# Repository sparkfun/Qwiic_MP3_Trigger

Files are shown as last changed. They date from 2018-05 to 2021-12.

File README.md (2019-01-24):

SparkFun Qwiic MP3 Trigger
========================================

SparkFun Qwiic MP3 Trigger

[*SparkFun Qwiic MP3 Trigger (DEV-15165)*](https://www.sparkfun.com/products/15165)

This repo is the hardware repo for the Qwiic MP3 Trigger.

Sometimes you just need an MP3 to play. Whether it's a theme song as you enter the room or a pirate cackling when a dollar [gets donated](https://github.com/nseidle/Money_Vacuum) to the kid's museum. The Qwiic MP3 Trigger takes care of all the necessary bits, all you need to do is send a simple I2C command and listen.

The Qwiic MP3 Trigger comes loaded with everything a user may need. Connecting a USB C cable enumerates the Qwiic MP3 Trigger as a jump drive. Simply plug in the Qwiic MP3 Trigger and you'll be transferring MP3s. No need for drivers and no need for WAV or Vorbis conversion! Sound output is provided via a headphone jack or poke-home connector allowing an external speaker to be connected without soldering. The speaker is boosted by a Class-D mono amplifier capable of outputting up to 1.4W. What does 1.4W mean? It's incredibly loud; great for making sure your mech effects are heard on the *con floor and wonderful for annoying your officemates. Volume is software selectable between 32 levels. Equalization can be tuned to be sure your classical hits sound different from your jazz dance routines (in all seriousness EQ selection is available but it's pretty paltry).

And if you don't want to deal with *any* programming, there are four trigger pins. When pin 3 is pulled low the T003.mp3 file will immediately be played. This allows you to start playing sound effects with the touch of a button! By pulling multiple pins down simultaneously the four triggers can play up to ten tracks: T001 to T010.

All settings including volume, EQ, and I2C address are stored in NVM and loaded at each power up. The I2C address of the Qwiic MP3 Trigger can be modified via a solder jumper or be assigned using a software command. Multiple Qwiic MP3 Triggers can be chained together on a single bus allowing for simultaneous track mixing and triggering.

We've written an extensive Arduino library to make MP3 playing over I2C a breeze. Play track X, change volume, play next/previous, check if track is playing, stop play, change EQ, and change I2C address are all supported.

The I2C address of Qwiic MP3 Trigger is software configurable which means you can hookup over 100 on a single I2C bus!

This board is one of our many [Qwiic](https://www.sparkfun.com/qwiic) compatible boards! Simply plug and go. No soldering, no figuring out which is SDA or SCL, and no voltage regulation or translation required!

SparkFun labored with love to create this code. Feel like supporting open source hardware? 
Buy a [breakout board](https://www.sparkfun.com/products/15165) from SparkFun!

Repository Contents
-------------------

* **/Documents** - Datasheets
* **/Hardware** - Eagle design files (.brd, .sch)

Documentation
--------------
* **[Qwiic MP3 Trigger Hookup Guide](https://learn.sparkfun.com/tutorials/qwiic-mp3-trigger-hookup-guide)** - Hookup guide for the Qwiic MP3 Trigger
* **[Installing an Arduino Library Guide](https://learn.sparkfun.com/tutorials/installing-an-arduino-library)** - Basic information on how to install an Arduino library.
* **[Arduino Library](https://github.com/sparkfun/SparkFun_Qwiic_MP3_Trigger_Arduino_Library)** - Library if you decide to use an Arduino via serial I2C.

License Information
-------------------

This product is _**open source**_! 

If you have any questions or concerns on licensing, please contact techsupport@sparkfun.com.

Please use, reuse, and modify these files as you see fit. Please maintain attribution to SparkFun Electronics and release any derivative under the same license.

Distributed as-is; no warranty is given.

- Your friends at SparkFun.

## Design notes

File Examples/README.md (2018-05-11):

SparkFun Qwiic MP3 Trigger
========================================

These various example sketches for Arduino demostrating how to use the Qwiic MP3 Trigger.

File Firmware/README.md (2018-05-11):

SparkFun Qwiic MP3 Trigger
========================================

This is the production firmware loaded onto the ATtiny84 on the QMP3T. The tester is an Arduino sketch used in production which causes the QMP3T to start playing. It's helpful to verify all the bits of the board are working.

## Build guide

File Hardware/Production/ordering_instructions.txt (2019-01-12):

panel size, 244x116mm
PCB thickness, 1.6mm
number of layers, 2
soldermask color, Red
silkscreen color, White
oz copper, 1oz
finish, HASL lead free
stencils, top
pcs per panel, 16

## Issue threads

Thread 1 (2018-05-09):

P10 pin not working

nseidle, 2018-05-09:
Pin is low at power up. Goes high during play. But stays high after song is stopped. This causes the amp to stay enabled after a song is complete and causes buzzing.

The BUSY pin does work as expected. Perhaps we wire the BUSY pin to the amp SDN pin.

nseidle, 2018-11-29:
Should be fixed on v10

Closed 2018-11-29.

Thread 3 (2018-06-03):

Documentation in firmware has incorrect i2c command values

querry43, 2018-06-03:
The comment header for Qwiic_MP3_Controller.ino lists the command values incorrectly.  As one example, it has:

> 0x0A : Get firmware version : 2 bytes, upper ver and lower ver

when the actual value is:

> #define COMMAND_GET_VERSION 0x0C

nseidle, 2018-06-04:
Good catch! Thanks for reporting the issue. I think I've updated the main firmware ino with the correct commands. Let me know if there's anything else that has issues.

Closed 2018-06-04.

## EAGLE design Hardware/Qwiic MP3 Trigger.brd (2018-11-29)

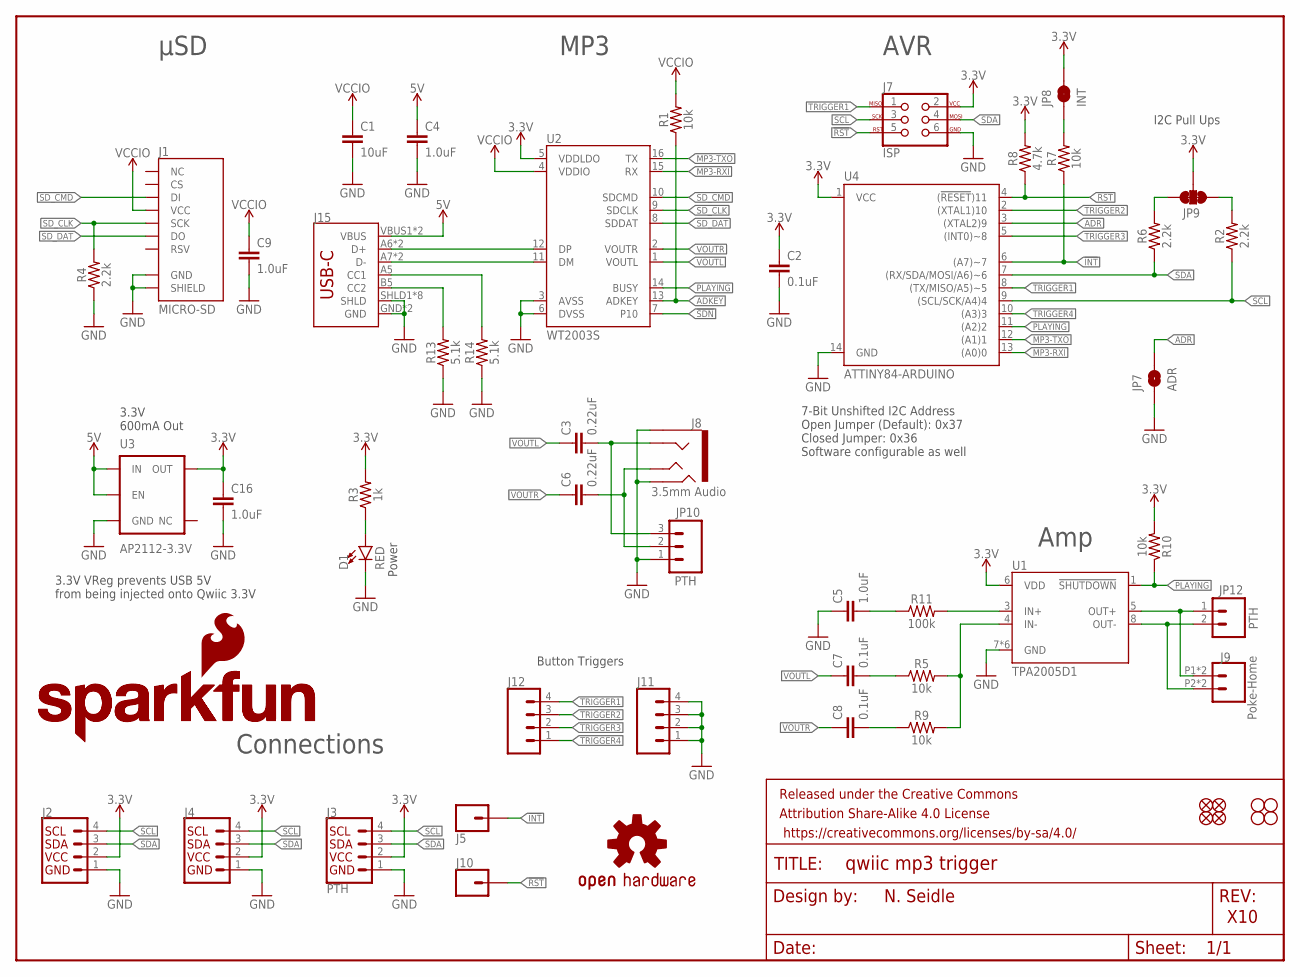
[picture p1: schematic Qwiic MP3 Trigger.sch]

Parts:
C1: 10uF; 0603
C2, C7, C8: 0.1uF; 0603
C3, C6: 0.22uF; 0603
C4, C5, C9, C16: 1.0uF; 0603
D1: RED; LED-0603
FRAME1: FRAME-LETTER; CREATIVE_COMMONS
J1: MICRO-SD; MICRO-SD-SOCKET
J2, J4: QWIIC_CONNECTORJS-1MM; 1X04_1MM_RA
J3: PTH; 1X04_NO_SILK
J5, J10: CONN_01PTH_NO_SILK_YES_STOP; 1X01_NO_SILK
J7: ISP; 2X3_TEST_POINTS
J8: 3.5mm Audio; AUDIO_JACK_3.5MM_TRRS_SMD_RA
J9: Poke-Home; 1X02_POKEHOME
J11, J12: CONN_041X04_NO_SILK; 1X04_NO_SILK
J15: USB_C16PIN; USB-C-16P
JP1, JP2, JP5, JP6: FIDUCIALUFIDUCIAL; MICRO-FIDUCIAL
JP3, JP4, JP11, JP13: STAND-OFF
JP7: ADR; SMT-JUMPER_2_NO_SILK
JP8: INT; SMT-JUMPER_2_NC_TRACE_SILK
JP9: JUMPER-SMT_3_2-NC_TRACE_SILK; SMT-JUMPER_3_2-NC_TRACE_SILK
JP10: PTH; 1X03_NO_SILK
JP12: PTH; 1X02_NO_SILK
LOGO1: OSHW-LOGOMINI; OSHW-LOGO-MINI
LOGO2: SFE_LOGO_NAME.1_INCH; SFE_LOGO_NAME_.1
LOGO3: SFE_LOGO_NAME_FLAME.1_INCH; SFE_LOGO_NAME_FLAME_.1
R1, R5, R7, R9, R10: 10k; 0603
R2, R4, R6: 2.2k; 0603
R3: 1k; 0603
R8: 4.7k; 0603
R11: 100k; 0603
R13, R14: 5.1k; 0603
U1: TPA2005D1; QFN-8_PAD
U2: WT2003S; SO16
U3: AP2112-3.3V; SOT23-5
U4: ATTINY84-ARDUINO; SO14

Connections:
3.3V: C2.1, C16.1, J2.2, J3.2 (VCC), J4.2, J7.2, JP8.2, JP9.2, R3.2, R8.2, R10.2, U1.6 (VDD), U2.5 (VDDLDO), U3.5 (OUT), U4.1 (VCC)
5V: C4.1, J15.VBUS1 (VBUS), J15.VBUS2 (VBUS), U3.1 (IN), U3.3 (EN)
!INT: J5.1, R7.1, U4.6 ((A7)~7)
!RST: J7.5, J10.1, R8.1, U4.4 ((!RESET!)11)
!SDN: U2.7 (P10)
AC-L: C3.2, J8.RING1, JP10.3
AC-R: C6.2, J8.TIP, JP10.2
ADKEY: R1.1, U2.13 (ADKEY)
ADR: JP7.2, U4.3 ((XTAL2)9)
D+: J15.A6 (D+), J15.B6 (D+), U2.12 (DP)
D-: J15.A7 (D-), J15.B7 (D-), U2.11 (DM)
GND: C1.2, C2.2, C4.2, C5.1, C9.2, C16.2, D1.C, J1.CD1 (SHIELD), J1.GND, J2.1, J3.1 (GND), J4.1, J7.6, J8.EARTH, J8.RING2, J11.1, J11.2, J11.3, J11.4, J15.GND, J15.GND2 (GND), J15.SHLD1 (SHLD), J15.SHLD2 (SHLD), J15.SHLD3 (SHLD), J15.SHLD4 (SHLD), J15.SHLD5 (SHLD), J15.SHLD6 (SHLD), J15.SHLD7 (SHLD), J15.SHLD8 (SHLD), JP7.1, JP10.1, R4.1, R13.1, R14.1, U1.7 (GND), U1.9 (GND), U1.10 (GND), U1.11 (GND), U1.12 (GND), U1.13 (GND), U2.3 (AVSS), U2.6 (DVSS), U3.2 (GND), U4.14 (GND)
IN+AMP: R11.2, U1.3 (IN+)
IN-AMP: R5.2, R9.2, U1.4 (IN-)
MP3-RXI: U2.15 (RX), U4.13 ((A0)0)
MP3-TXO: U2.16 (TX), U4.12 ((A1)1)
unnamed: J15.B5 (CC2), R13.2
unnamed: J15.A5 (CC1), R14.2
unnamed: D1.A, R3.1
unnamed: JP8.1, R7.2
unnamed: C8.2, R9.1
unnamed: C5.2, R11.1
unnamed: C7.2, R5.1
OUT+: J9.P1 (1), J9.P3 (1), JP12.1, U1.5 (OUT+)
OUT-: J9.P2 (2), J9.P4 (2), JP12.2, U1.8 (OUT-)
PLAYING: R10.1, U1.1 (!SHUTDOWN), U2.14 (BUSY), U4.11 ((A2)2)
SCL: J2.4, J3.4 (SCL), J4.4, J7.3, R2.1, U4.9 ((SCL/SCK/A4)4)
SCL_PU1: JP9.1, R2.2
SDA: J2.3, J3.3 (SDA), J4.3, J7.4, R6.1, U4.7 ((RX/SDA/MOSI/A6)~6)
SDA_PU1: JP9.3, R6.2
SD_CLK: J1.SCLK (SCK), R4.2, U2.9 (SDCLK)
SD_CMD: J1.DI, U2.10 (SDCMD)
SD_DAT: J1.DO, U2.8 (SDDAT)
TRIGGER1: J7.1, J12.4, U4.8 ((TX/MISO/A5)~5)
TRIGGER2: J12.3, U4.2 ((XTAL1)10)
TRIGGER3: J12.2, U4.5 ((INT0)~8)
TRIGGER4: J12.1, U4.10 ((A3)3)
VCCIO: C1.1, C9.1, J1.VCC, R1.2, U2.4 (VDDIO)
VOUTL: C3.1, C7.1, U2.1 (VOUTL)
VOUTR: C6.1, C8.1, U2.2 (VOUTR)

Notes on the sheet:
N. Seidle
X10
Power
7-Bit Unshifted I2C Address Open Jumper (Default): 0x37 Closed Jumper: 0x36 Software configurable as well
I2C Pull Ups
Button Triggers
3.3V VReg prevents USB 5V from being injected onto Qwiic 3.3V
3.3V 600mA Out
μSD
MP3
AVR
Amp
Connections

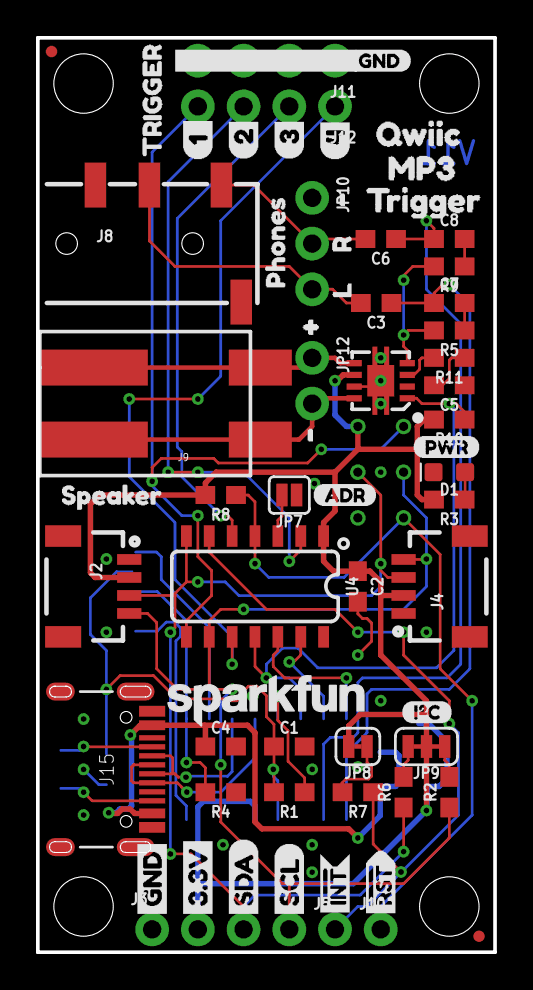
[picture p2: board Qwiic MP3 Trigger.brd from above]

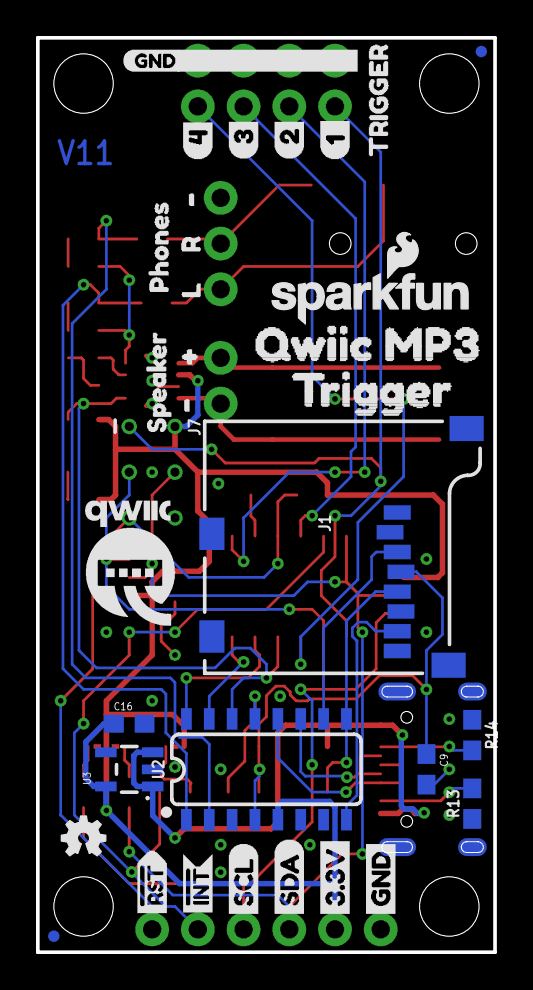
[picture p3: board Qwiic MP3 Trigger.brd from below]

Board: 2 copper layers, 25.4 x 50.8 mm, 104 parts (34 on the bottom side), 39 nets.

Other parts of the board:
U$1: MP31
U$3, U$22: GND1
U$4, U$21: 3#3V2
U$5, U$27: SDA8
U$6, U$26: SCL9
U$7, U$16: RST#-[>
U$8: I_SUPER2_C-()-03
U$9, U$11: INT#-[<
U$10, U$13, U$25, U$38: #6
U$12, U$28: #5
U$14, U$20: SPEAKER1
U$15, U$40: PHONES0
U$17: PWR-()-03
U$18: ADR-()-03
U$19, U$44: 1_1
U$23: QWIIC0
U$24: QWIIC_MP32
U$29, U$45: TRIGGER5
U$31, U$34: 43
U$32, U$42: 21
U$33, U$36: 32
U$35, U$46: GND0
U$37, U$41: L12
U$39, U$43: R11
U$47: QWIIC-LOGO-MEDIUM
U$49: TRIGGER4
U$50: TRIGGER2

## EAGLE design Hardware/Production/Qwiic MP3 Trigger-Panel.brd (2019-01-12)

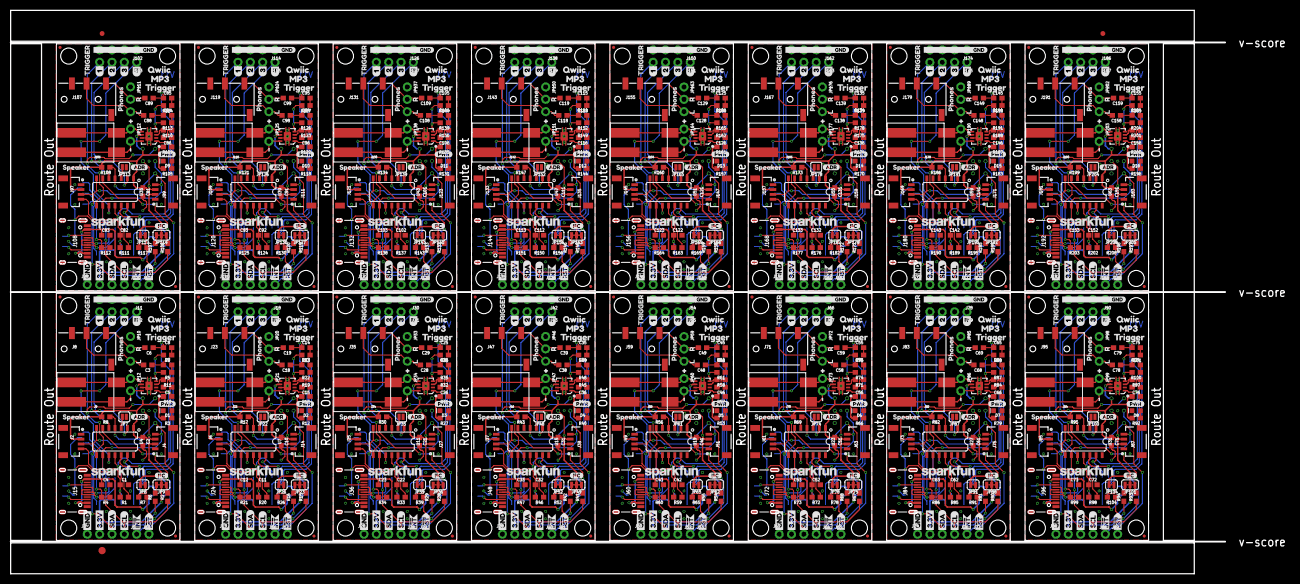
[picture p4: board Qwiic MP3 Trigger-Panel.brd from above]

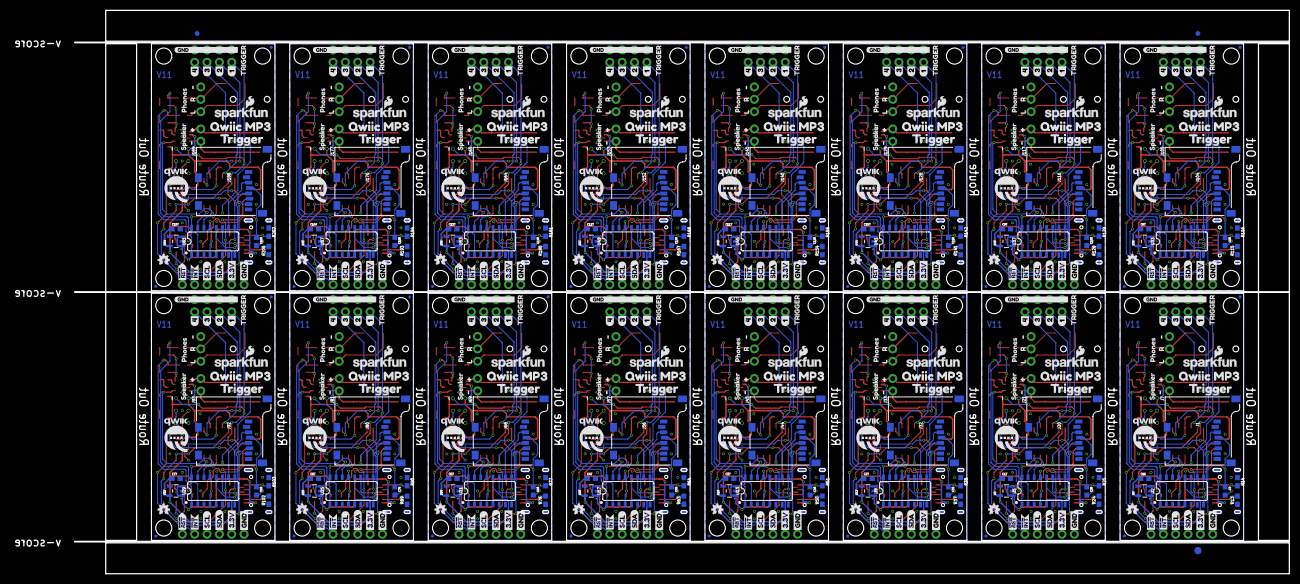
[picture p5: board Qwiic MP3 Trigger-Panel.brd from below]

Board: 2 copper layers, 249.7 x 115.8 mm, 1654 parts (547 on the bottom side), 624 nets.

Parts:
C1, C11, C22, C32, C42, C52, C62, C72, C82, C92, C102, C112, C122, C132, C142, C152: 10uF; 0603
C2, C7, C8, C10, C13, C14, C21, C24, C25, C31, C34, C35, C41, C44, C45, C51, C54, C55, C61, C64, C65, C71, C74, C75, C81, C84, C85, C91, C94, C95, C101, C104, C105, C111, C114, C115, C121, C124, C125, C131, C134, C135, C141, C144, C145, C151, C154, C155: 0.1uF; 0603
C3, C6, C18, C19, C28, C29, C38, C39, C48, C49, C58, C59, C68, C69, C78, C79, C88, C89, C98, C99, C108, C109, C118, C119, C128, C129, C138, C139, C148, C149, C158, C159: 0.22uF; 0603
C4, C5, C9, C12, C15, C16, C17, C20, C23, C26, C27, C30, C33, C36, C37, C40, C43, C46, C47, C50, C53, C56, C57, C60, C63, C66, C67, C70, C73, C76, C77, C80, C83, C86, C87, C90, C93, C96, C97, C100, C103, C106, C107, C110, C113, C116, C117, C120, C123, C126, C127, C130, C133, C136, C137, C140, C143, C146, C147, C150, C153, C156, C157, C160: 1.0uF; 0603
D1, D2, D3, D4, D5, D6, D7, D8, D9, D10, D11, D12, D13, D14, D15, D16: RED; LED-0603
E$1, E$2, E$3, E$4: FIDUCIAL-1X2
E$5, E$6: FIDUCIAL-1.5X3
J1, J20, J32, J44, J56, J68, J80, J92, J104, J116, J128, J140, J152, J164, J176, J188: MICRO-SD; MICRO-SD-SOCKET
J2, J4, J6, J14, J25, J27, J37, J39, J49, J51, J61, J63, J73, J75, J85, J87, J97, J99, J109, J111, J121, J123, J133, J135, J145, J147, J157, J159, J169, J171, J181, J183: 1X04_1MM_RA
J3, J13, J26, J38, J50, J62, J74, J86, J98, J110, J122, J134, J146, J158, J170, J182: PTH; 1X04_NO_SILK
J5, J10, J16, J17, J28, J29, J40, J41, J52, J53, J64, J65, J76, J77, J88, J89, J100, J101, J112, J113, J124, J125, J136, J137, J148, J149, J160, J161, J172, J173, J184, J185: 1X01_NO_SILK
J7, J21, J33, J45, J57, J69, J81, J93, J105, J117, J129, J141, J153, J165, J177, J189: ISP; 2X3_TEST_POINTS
J8, J23, J35, J47, J59, J71, J83, J95, J107, J119, J131, J143, J155, J167, J179, J191: 3.5mm Audio; AUDIO_JACK_3.5MM_TRRS_SMD_RA
J9, J22, J34, J46, J58, J70, J82, J94, J106, J118, J130, J142, J154, J166, J178, J190: Poke-Home; 1X02_POKEHOME
J11, J12, J18, J19, J30, J31, J42, J43, J54, J55, J66, J67, J78, J79, J90, J91, J102, J103, J114, J115, J126, J127, J138, J139, J150, J151, J162, J163, J174, J175, J186, J187: 1X04_NO_SILK
J15, J24, J36, J48, J60, J72, J84, J96, J108, J120, J132, J144, J156, J168, J180, J192: USB-C-16P
JP1, JP2, JP5, JP6, JP16, JP17, JP18, JP19, JP29, JP30, JP31, JP32, JP42, JP43, JP44, JP45, JP55, JP56, JP57, JP58, JP68, JP69, JP70, JP71, JP81, JP82, JP83, JP84, JP94, JP95, JP96, JP97, JP107, JP108, JP109, JP110, JP120, JP121, JP122, JP123, JP133, JP134, JP135, JP136, JP146, JP147, JP148, JP149, JP159, JP160, JP161, JP162, JP172, JP173, JP174, JP175, JP185, JP186, JP187, JP188, JP198, JP199, JP200, JP201: FIDUCIALUFIDUCIAL; MICRO-FIDUCIAL
JP3, JP4, JP11, JP13, JP14, JP15, JP24, JP25, JP27, JP28, JP37, JP38, JP40, JP41, JP50, JP51, JP53, JP54, JP63, JP64, JP66, JP67, JP76, JP77, JP79, JP80, JP89, JP90, JP92, JP93, JP102, JP103, JP105, JP106, JP115, JP116, JP118, JP119, JP128, JP129, JP131, JP132, JP141, JP142, JP144, JP145, JP154, JP155, JP157, JP158, JP167, JP168, JP170, JP171, JP180, JP181, JP183, JP184, JP193, JP194, JP196, JP197, JP206, JP207: STAND-OFF
JP7, JP22, JP35, JP48, JP61, JP74, JP87, JP100, JP113, JP126, JP139, JP152, JP165, JP178, JP191, JP204: ADR; SMT-JUMPER_2_NO_SILK
JP8, JP26, JP39, JP52, JP65, JP78, JP91, JP104, JP117, JP130, JP143, JP156, JP169, JP182, JP195, JP208: INT; SMT-JUMPER_2_NC_TRACE_SILK
JP9, JP23, JP36, JP49, JP62, JP75, JP88, JP101, JP114, JP127, JP140, JP153, JP166, JP179, JP192, JP205: SMT-JUMPER_3_2-NC_TRACE_SILK
JP10, JP20, JP33, JP46, JP59, JP72, JP85, JP98, JP111, JP124, JP137, JP150, JP163, JP176, JP189, JP202: PTH; 1X03_NO_SILK
JP12, JP21, JP34, JP47, JP60, JP73, JP86, JP99, JP112, JP125, JP138, JP151, JP164, JP177, JP190, JP203: PTH; 1X02_NO_SILK
LOGO1, LOGO4, LOGO7, LOGO10, LOGO13, LOGO16, LOGO19, LOGO22, LOGO25, LOGO28, LOGO31, LOGO34, LOGO37, LOGO40, LOGO43, LOGO46: OSHW-LOGOMINI; OSHW-LOGO-MINI
LOGO2, LOGO5, LOGO8, LOGO11, LOGO14, LOGO17, LOGO20, LOGO23, LOGO26, LOGO29, LOGO32, LOGO35, LOGO38, LOGO41, LOGO44, LOGO47: SFE_LOGO_NAME.1_INCH; SFE_LOGO_NAME_.1
LOGO3, LOGO6, LOGO9, LOGO12, LOGO15, LOGO18, LOGO21, LOGO24, LOGO27, LOGO30, LOGO33, LOGO36, LOGO39, LOGO42, LOGO45, LOGO48: SFE_LOGO_NAME_FLAME.1_INCH; SFE_LOGO_NAME_FLAME_.1
R1, R5, R7, R9, R10, R18, R20, R22, R23, R26, R31, R33, R35, R36, R39, R44, R46, R48, R49, R52, R57, R59, R61, R62, R65, R70, R72, R74, R75, R78, R83, R85, R87, R88, R91, R96, R98, R100, R101, R104, R109, R111, R113, R114, R117, R122, R124, R126, R127, R130, R135, R137, R139, R140, R143, R148, R150, R152, R153, R156, R161, R163, R165, R166, R169, R174, R176, R178, R179, R182, R187, R189, R191, R192, R195, R200, R202, R204, R205, R208: 10k; 0603
R2, R4, R6, R15, R16, R21, R28, R29, R34, R41, R42, R47, R54, R55, R60, R67, R68, R73, R80, R81, R86, R93, R94, R99, R106, R107, R112, R119, R120, R125, R132, R133, R138, R145, R146, R151, R158, R159, R164, R171, R172, R177, R184, R185, R190, R197, R198, R203: 2.2k; 0603
R3, R12, R27, R40, R53, R66, R79, R92, R105, R118, R131, R144, R157, R170, R183, R196: 1k; 0603
R8, R17, R30, R43, R56, R69, R82, R95, R108, R121, R134, R147, R160, R173, R186, R199: 4.7k; 0603
R11, R19, R32, R45, R58, R71, R84, R97, R110, R123, R136, R149, R162, R175, R188, R201: 100k; 0603
R13, R14, R24, R25, R37, R38, R50, R51, R63, R64, R76, R77, R89, R90, R102, R103, R115, R116, R128, R129, R141, R142, R154, R155, R167, R168, R180, R181, R193, R194, R206, R207: 5.1k; 0603
U1, U6, U10, U14, U18, U22, U26, U30, U34, U38, U42, U46, U50, U54, U58, U62: TPA2005D1; QFN-8_PAD
U2, U5, U9, U13, U17, U21, U25, U29, U33, U37, U41, U45, U49, U53, U57, U61: WT2003S; SO16
U3, U8, U12, U16, U20, U24, U28, U32, U36, U40, U44, U48, U52, U56, U60, U64: AP2112-3.3V; SOT23-5
U4, U7, U11, U15, U19, U23, U27, U31, U35, U39, U43, U47, U51, U55, U59, U63: ATTINY84-ARDUINO; SO14
U$1, U$92, U$139, U$186, U$233, U$280, U$327, U$374, U$421, U$468, U$515, U$562, U$609, U$656, U$703, U$750: MP31
U$2, U$4, U$21, U$53, U$95, U$100, U$142, U$147, U$189, U$194, U$236, U$241, U$283, U$288, U$330, U$335, U$377, U$382, U$424, U$429, U$471, U$476, U$518, U$523, U$565, U$570, U$612, U$617, U$659, U$664, U$706, U$711: 3#3V2
U$3, U$22, U$30, U$52, U$96, U$99, U$143, U$146, U$190, U$193, U$237, U$240, U$284, U$287, U$331, U$334, U$378, U$381, U$425, U$428, U$472, U$475, U$519, U$522, U$566, U$569, U$613, U$616, U$660, U$663, U$707, U$710: GND1
U$5, U$27, U$51, U$54, U$98, U$101, U$145, U$148, U$192, U$195, U$239, U$242, U$286, U$289, U$333, U$336, U$380, U$383, U$427, U$430, U$474, U$477, U$521, U$524, U$568, U$571, U$615, U$618, U$662, U$665, U$709, U$712: SDA8
U$6, U$26, U$48, U$55, U$97, U$102, U$144, U$149, U$191, U$196, U$238, U$243, U$285, U$290, U$332, U$337, U$379, U$384, U$426, U$431, U$473, U$478, U$520, U$525, U$567, U$572, U$614, U$619, U$661, U$666, U$708, U$713: SCL9
U$7, U$16, U$59, U$60, U$106, U$107, U$153, U$154, U$200, U$201, U$247, U$248, U$294, U$295, U$341, U$342, U$388, U$389, U$435, U$436, U$482, U$483, U$529, U$530, U$576, U$577, U$623, U$624, U$670, U$671, U$717, U$718: RST#-[>
U$8, U$56, U$103, U$150, U$197, U$244, U$291, U$338, U$385, U$432, U$479, U$526, U$573, U$620, U$667, U$714: I_SUPER2_C-()-03
U$9, U$11, U$57, U$58, U$104, U$105, U$151, U$152, U$198, U$199, U$245, U$246, U$292, U$293, U$339, U$340, U$386, U$387, U$433, U$434, U$480, U$481, U$527, U$528, U$574, U$575, U$621, U$622, U$668, U$669, U$715, U$716: INT#-[<
U$10, U$13, U$25, U$38, U$68, U$73, U$77, U$81, U$115, U$120, U$124, U$128, U$162, U$167, U$171, U$175, U$209, U$214, U$218, U$222, U$256, U$261, U$265, U$269, U$303, U$308, U$312, U$316, U$350, U$355, U$359, U$363, U$397, U$402, U$406, U$410, U$444, U$449, U$453, U$457, U$491, U$496, U$500, U$504, U$538, U$543, U$547, U$551, U$585, U$590, U$594, U$598, U$632, U$637, U$641, U$645, U$679, U$684, U$688, U$692, U$726, U$731, U$735, U$739: #6
U$12, U$28, U$67, U$78, U$114, U$125, U$161, U$172, U$208, U$219, U$255, U$266, U$302, U$313, U$349, U$360, U$396, U$407, U$443, U$454, U$490, U$501, U$537, U$548, U$584, U$595, U$631, U$642, U$678, U$689, U$725, U$736: #5
U$14, U$20, U$75, U$89, U$122, U$136, U$169, U$183, U$216, U$230, U$263, U$277, U$310, U$324, U$357, U$371, U$404, U$418, U$451, U$465, U$498, U$512, U$545, U$559, U$592, U$606, U$639, U$653, U$686, U$700, U$733, U$747: SPEAKER1
U$15, U$40, U$74, U$88, U$121, U$135, U$168, U$182, U$215, U$229, U$262, U$276, U$309, U$323, U$356, U$370, U$403, U$417, U$450, U$464, U$497, U$511, U$544, U$558, U$591, U$605, U$638, U$652, U$685, U$699, U$732, U$746: PHONES0
U$17, U$61, U$108, U$155, U$202, U$249, U$296, U$343, U$390, U$437, U$484, U$531, U$578, U$625, U$672, U$719: PWR-()-03
U$18, U$62, U$109, U$156, U$203, U$250, U$297, U$344, U$391, U$438, U$485, U$532, U$579, U$626, U$673, U$720: ADR-()-03
U$19, U$44, U$69, U$85, U$116, U$132, U$163, U$179, U$210, U$226, U$257, U$273, U$304, U$320, U$351, U$367, U$398, U$414, U$445, U$461, U$492, U$508, U$539, U$555, U$586, U$602, U$633, U$649, U$680, U$696, U$727, U$743: 1_1
U$23, U$93, U$140, U$187, U$234, U$281, U$328, U$375, U$422, U$469, U$516, U$563, U$610, U$657, U$704, U$751: QWIIC0
U$24, U$76, U$123, U$170, U$217, U$264, U$311, U$358, U$405, U$452, U$499, U$546, U$593, U$640, U$687, U$734: QWIIC_MP32
U$29, U$45, U$63, U$86, U$110, U$133, U$157, U$180, U$204, U$227, U$251, U$274, U$298, U$321, U$345, U$368, U$392, U$415, U$439, U$462, U$486, U$509, U$533, U$556, U$580, U$603, U$627, U$650, U$674, U$697, U$721, U$744: TRIGGER5
U$31, U$34, U$66, U$79, U$113, U$126, U$160, U$173, U$207, U$220, U$254, U$267, U$301, U$314, U$348, U$361, U$395, U$408, U$442, U$455, U$489, U$502, U$536, U$549, U$583, U$596, U$630, U$643, U$677, U$690, U$724, U$737: 43
U$32, U$42, U$64, U$84, U$111, U$131, U$158, U$178, U$205, U$225, U$252, U$272, U$299, U$319, U$346, U$366, U$393, U$413, U$440, U$460, U$487, U$507, U$534, U$554, U$581, U$601, U$628, U$648, U$675, U$695, U$722, U$742: 21
U$33, U$36, U$65, U$80, U$112, U$127, U$159, U$174, U$206, U$221, U$253, U$268, U$300, U$315, U$347, U$362, U$394, U$409, U$441, U$456, U$488, U$503, U$535, U$550, U$582, U$597, U$629, U$644, U$676, U$691, U$723, U$738: 32
U$35, U$46, U$70, U$87, U$117, U$134, U$164, U$181, U$211, U$228, U$258, U$275, U$305, U$322, U$352, U$369, U$399, U$416, U$446, U$463, U$493, U$510, U$540, U$557, U$587, U$604, U$634, U$651, U$681, U$698, U$728, U$745: GND0
U$37, U$41, U$71, U$83, U$118, U$130, U$165, U$177, U$212, U$224, U$259, U$271, U$306, U$318, U$353, U$365, U$400, U$412, U$447, U$459, U$494, U$506, U$541, U$553, U$588, U$600, U$635, U$647, U$682, U$694, U$729, U$741: L12
U$39, U$43, U$72, U$82, U$119, U$129, U$166, U$176, U$213, U$223, U$260, U$270, U$307, U$317, U$354, U$364, U$401, U$411, U$448, U$458, U$495, U$505, U$542, U$552, U$589, U$599, U$636, U$646, U$683, U$693, U$730, U$740: R11
U$47, U$90, U$137, U$184, U$231, U$278, U$325, U$372, U$419, U$466, U$513, U$560, U$607, U$654, U$701, U$748: QWIIC-LOGO-MEDIUM
U$49, U$91, U$138, U$185, U$232, U$279, U$326, U$373, U$420, U$467, U$514, U$561, U$608, U$655, U$702, U$749: TRIGGER4
U$50, U$94, U$141, U$188, U$235, U$282, U$329, U$376, U$423, U$470, U$517, U$564, U$611, U$658, U$705, U$752: TRIGGER2

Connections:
3.3V: C2.1, C16.1, J2.2, J3.2, J4.2, J7.2, JP8.2, JP9.2, R3.2, R8.2, R10.2, U1.6, U2.5, U3.5, U4.1
3.3V1: C10.1, C17.1, J6.2, J13.2, J14.2, J21.2, JP23.2, JP26.2, R12.2, R17.2, R18.2, U5.5, U6.6, U7.1, U8.5
3.3V2: C21.1, C27.1, J25.2, J26.2, J27.2, J33.2, JP36.2, JP39.2, R27.2, R30.2, R31.2, U9.5, U10.6, U11.1, U12.5
3.3V3: C31.1, C37.1, J37.2, J38.2, J39.2, J45.2, JP49.2, JP52.2, R40.2, R43.2, R44.2, U13.5, U14.6, U15.1, U16.5
3.3V4: C41.1, C47.1, J49.2, J50.2, J51.2, J57.2, JP62.2, JP65.2, R53.2, R56.2, R57.2, U17.5, U18.6, U19.1, U20.5
3.3V5: C51.1, C57.1, J61.2, J62.2, J63.2, J69.2, JP75.2, JP78.2, R66.2, R69.2, R70.2, U21.5, U22.6, U23.1, U24.5
3.3V6: C61.1, C67.1, J73.2, J74.2, J75.2, J81.2, JP88.2, JP91.2, R79.2, R82.2, R83.2, U25.5, U26.6, U27.1, U28.5
3.3V7: C71.1, C77.1, J85.2, J86.2, J87.2, J93.2, JP101.2, JP104.2, R92.2, R95.2, R96.2, U29.5, U30.6, U31.1, U32.5
3.3V8: C81.1, C87.1, J97.2, J98.2, J99.2, J105.2, JP114.2, JP117.2, R105.2, R108.2, R109.2, U33.5, U34.6, U35.1, U36.5
3.3V9: C91.1, C97.1, J109.2, J110.2, J111.2, J117.2, JP127.2, JP130.2, R118.2, R121.2, R122.2, U37.5, U38.6, U39.1, U40.5
3.3V10: C101.1, C107.1, J121.2, J122.2, J123.2, J129.2, JP140.2, JP143.2, R131.2, R134.2, R135.2, U41.5, U42.6, U43.1, U44.5
3.3V11: C111.1, C117.1, J133.2, J134.2, J135.2, J141.2, JP153.2, JP156.2, R144.2, R147.2, R148.2, U45.5, U46.6, U47.1, U48.5
3.3V12: C121.1, C127.1, J145.2, J146.2, J147.2, J153.2, JP166.2, JP169.2, R157.2, R160.2, R161.2, U49.5, U50.6, U51.1, U52.5
3.3V13: C131.1, C137.1, J157.2, J158.2, J159.2, J165.2, JP179.2, JP182.2, R170.2, R173.2, R174.2, U53.5, U54.6, U55.1, U56.5
3.3V14: C141.1, C147.1, J169.2, J170.2, J171.2, J177.2, JP192.2, JP195.2, R183.2, R186.2, R187.2, U57.5, U58.6, U59.1, U60.5
3.3V15: C151.1, C157.1, J181.2, J182.2, J183.2, J189.2, JP205.2, JP208.2, R196.2, R199.2, R200.2, U61.5, U62.6, U63.1, U64.5
5V: C4.1, J15.VBUS1, J15.VBUS2, U3.1, U3.3
5V1: C12.1, J24.VBUS1, J24.VBUS2, U8.1, U8.3
5V2: C23.1, J36.VBUS1, J36.VBUS2, U12.1, U12.3
5V3: C33.1, J48.VBUS1, J48.VBUS2, U16.1, U16.3
5V4: C43.1, J60.VBUS1, J60.VBUS2, U20.1, U20.3
5V5: C53.1, J72.VBUS1, J72.VBUS2, U24.1, U24.3
5V6: C63.1, J84.VBUS1, J84.VBUS2, U28.1, U28.3
5V7: C73.1, J96.VBUS1, J96.VBUS2, U32.1, U32.3
5V8: C83.1, J108.VBUS1, J108.VBUS2, U36.1, U36.3
5V9: C93.1, J120.VBUS1, J120.VBUS2, U40.1, U40.3
5V10: C103.1, J132.VBUS1, J132.VBUS2, U44.1, U44.3
5V11: C113.1, J144.VBUS1, J144.VBUS2, U48.1, U48.3
5V12: C123.1, J156.VBUS1, J156.VBUS2, U52.1, U52.3
5V13: C133.1, J168.VBUS1, J168.VBUS2, U56.1, U56.3
5V14: C143.1, J180.VBUS1, J180.VBUS2, U60.1, U60.3
5V15: C153.1, J192.VBUS1, J192.VBUS2, U64.1, U64.3
!INT: J5.1, R7.1, U4.6
!INT1: J16.1, R26.1, U7.6
!INT2: J28.1, R39.1, U11.6
!INT3: J40.1, R52.1, U15.6
!INT4: J52.1, R65.1, U19.6
!INT5: J64.1, R78.1, U23.6
!INT6: J76.1, R91.1, U27.6
!INT7: J88.1, R104.1, U31.6
!INT8: J100.1, R117.1, U35.6
!INT9: J112.1, R130.1, U39.6
!INT10: J124.1, R143.1, U43.6
!INT11: J136.1, R156.1, U47.6
!INT12: J148.1, R169.1, U51.6
!INT13: J160.1, R182.1, U55.6
!INT14: J172.1, R195.1, U59.6
!INT15: J184.1, R208.1, U63.6
!RST: J7.5, J10.1, R8.1, U4.4
!RST1: J17.1, J21.5, R17.1, U7.4
!RST2: J29.1, J33.5, R30.1, U11.4
!RST3: J41.1, J45.5, R43.1, U15.4
!RST4: J53.1, J57.5, R56.1, U19.4
!RST5: J65.1, J69.5, R69.1, U23.4
!RST6: J77.1, J81.5, R82.1, U27.4
!RST7: J89.1, J93.5, R95.1, U31.4
!RST8: J101.1, J105.5, R108.1, U35.4
!RST9: J113.1, J117.5, R121.1, U39.4
!RST10: J125.1, J129.5, R134.1, U43.4
!RST11: J137.1, J141.5, R147.1, U47.4
!RST12: J149.1, J153.5, R160.1, U51.4
!RST13: J161.1, J165.5, R173.1, U55.4
!RST14: J173.1, J177.5, R186.1, U59.4
!RST15: J185.1, J189.5, R199.1, U63.4
AC-L: C3.2, J8.RING1, JP10.3
AC-L1: C18.2, J23.RING1, JP20.3
AC-L2: C28.2, J35.RING1, JP33.3
AC-L3: C38.2, J47.RING1, JP46.3
AC-L4: C48.2, J59.RING1, JP59.3
AC-L5: C58.2, J71.RING1, JP72.3
AC-L6: C68.2, J83.RING1, JP85.3
AC-L7: C78.2, J95.RING1, JP98.3
AC-L8: C88.2, J107.RING1, JP111.3
AC-L9: C98.2, J119.RING1, JP124.3
AC-L10: C108.2, J131.RING1, JP137.3
AC-L11: C118.2, J143.RING1, JP150.3
AC-L12: C128.2, J155.RING1, JP163.3
AC-L13: C138.2, J167.RING1, JP176.3
AC-L14: C148.2, J179.RING1, JP189.3
AC-L15: C158.2, J191.RING1, JP202.3
AC-R: C6.2, J8.TIP, JP10.2
AC-R1: C19.2, J23.TIP, JP20.2
AC-R2: C29.2, J35.TIP, JP33.2
AC-R3: C39.2, J47.TIP, JP46.2
AC-R4: C49.2, J59.TIP, JP59.2
AC-R5: C59.2, J71.TIP, JP72.2
AC-R6: C69.2, J83.TIP, JP85.2
AC-R7: C79.2, J95.TIP, JP98.2
AC-R8: C89.2, J107.TIP, JP111.2
AC-R9: C99.2, J119.TIP, JP124.2
AC-R10: C109.2, J131.TIP, JP137.2
AC-R11: C119.2, J143.TIP, JP150.2
AC-R12: C129.2, J155.TIP, JP163.2
AC-R13: C139.2, J167.TIP, JP176.2
AC-R14: C149.2, J179.TIP, JP189.2
AC-R15: C159.2, J191.TIP, JP202.2
ADKEY: R1.1, U2.13
ADKEY1: R20.1, U5.13
ADKEY2: R33.1, U9.13
ADKEY3: R46.1, U13.13
ADKEY4: R59.1, U17.13
ADKEY5: R72.1, U21.13
ADKEY6: R85.1, U25.13
ADKEY7: R98.1, U29.13
ADKEY8: R111.1, U33.13
ADKEY9: R124.1, U37.13
ADKEY10: R137.1, U41.13
ADKEY11: R150.1, U45.13
ADKEY12: R163.1, U49.13
ADKEY13: R176.1, U53.13
ADKEY14: R189.1, U57.13
ADKEY15: R202.1, U61.13
ADR: JP7.2, U4.3
ADR1: JP22.2, U7.3
ADR2: JP35.2, U11.3
ADR3: JP48.2, U15.3
ADR4: JP61.2, U19.3
ADR5: JP74.2, U23.3
ADR6: JP87.2, U27.3
ADR7: JP100.2, U31.3
ADR8: JP113.2, U35.3
ADR9: JP126.2, U39.3
ADR10: JP139.2, U43.3
ADR11: JP152.2, U47.3
ADR12: JP165.2, U51.3
ADR13: JP178.2, U55.3
ADR14: JP191.2, U59.3
ADR15: JP204.2, U63.3
D+: J15.A6, J15.B6, U2.12
D+1: J24.A6, J24.B6, U5.12
D+2: J36.A6, J36.B6, U9.12
D+3: J48.A6, J48.B6, U13.12
D+4: J60.A6, J60.B6, U17.12
D+5: J72.A6, J72.B6, U21.12
D+6: J84.A6, J84.B6, U25.12
D+7: J96.A6, J96.B6, U29.12
D+8: J108.A6, J108.B6, U33.12
D+9: J120.A6, J120.B6, U37.12
D+10: J132.A6, J132.B6, U41.12
D+11: J144.A6, J144.B6, U45.12
D+12: J156.A6, J156.B6, U49.12
D+13: J168.A6, J168.B6, U53.12
D+14: J180.A6, J180.B6, U57.12
D+15: J192.A6, J192.B6, U61.12
D-: J15.A7, J15.B7, U2.11
D-1: J24.A7, J24.B7, U5.11
D-2: J36.A7, J36.B7, U9.11
D-3: J48.A7, J48.B7, U13.11
D-4: J60.A7, J60.B7, U17.11
D-5: J72.A7, J72.B7, U21.11
D-6: J84.A7, J84.B7, U25.11
D-7: J96.A7, J96.B7, U29.11
D-8: J108.A7, J108.B7, U33.11
D-9: J120.A7, J120.B7, U37.11
D-10: J132.A7, J132.B7, U41.11
D-11: J144.A7, J144.B7, U45.11
D-12: J156.A7, J156.B7, U49.11
D-13: J168.A7, J168.B7, U53.11
D-14: J180.A7, J180.B7, U57.11
D-15: J192.A7, J192.B7, U61.11
GND: C1.2, C2.2, C4.2, C5.1, C9.2, C16.2, D1.C, J1.CD1, J1.GND, J2.1, J3.1, J4.1, J7.6, J8.EARTH, J8.RING2, J11.1, J11.2, J11.3, J11.4, J15.GND, J15.GND2, J15.SHLD1, J15.SHLD2, J15.SHLD3, J15.SHLD4, J15.SHLD5, J15.SHLD6, J15.SHLD7, J15.SHLD8, JP7.1, JP10.1, R4.1, R13.1, R14.1, U1.7, U1.9, U1.10, U1.11, U1.12, U1.13, U2.3, U2.6, U3.2, U4.14
GND1: C10.2, C11.2, C12.2, C15.1, C17.2, C20.2, D2.C, J6.1, J13.1, J14.1, J18.1, J18.2, J18.3, J18.4, J20.CD1, J20.GND, J21.6, J23.EARTH, J23.RING2, J24.GND, J24.GND2, J24.SHLD1, J24.SHLD2, J24.SHLD3, J24.SHLD4, J24.SHLD5, J24.SHLD6, J24.SHLD7, J24.SHLD8, JP20.1, JP22.1, R21.1, R24.1, R25.1, U5.3, U5.6, U6.7, U6.9, U6.10, U6.11, U6.12, U6.13, U7.14, U8.2
GND2: C21.2, C22.2, C23.2, C26.1, C27.2, C30.2, D3.C, J25.1, J26.1, J27.1, J30.1, J30.2, J30.3, J30.4, J32.CD1, J32.GND, J33.6, J35.EARTH, J35.RING2, J36.GND, J36.GND2, J36.SHLD1, J36.SHLD2, J36.SHLD3, J36.SHLD4, J36.SHLD5, J36.SHLD6, J36.SHLD7, J36.SHLD8, JP33.1, JP35.1, R34.1, R37.1, R38.1, U9.3, U9.6, U10.7, U10.9, U10.10, U10.11, U10.12, U10.13, U11.14, U12.2
GND3: C31.2, C32.2, C33.2, C36.1, C37.2, C40.2, D4.C, J37.1, J38.1, J39.1, J42.1, J42.2, J42.3, J42.4, J44.CD1, J44.GND, J45.6, J47.EARTH, J47.RING2, J48.GND, J48.GND2, J48.SHLD1, J48.SHLD2, J48.SHLD3, J48.SHLD4, J48.SHLD5, J48.SHLD6, J48.SHLD7, J48.SHLD8, JP46.1, JP48.1, R47.1, R50.1, R51.1, U13.3, U13.6, U14.7, U14.9, U14.10, U14.11, U14.12, U14.13, U15.14, U16.2
GND4: C41.2, C42.2, C43.2, C46.1, C47.2, C50.2, D5.C, J49.1, J50.1, J51.1, J54.1, J54.2, J54.3, J54.4, J56.CD1, J56.GND, J57.6, J59.EARTH, J59.RING2, J60.GND, J60.GND2, J60.SHLD1, J60.SHLD2, J60.SHLD3, J60.SHLD4, J60.SHLD5, J60.SHLD6, J60.SHLD7, J60.SHLD8, JP59.1, JP61.1, R60.1, R63.1, R64.1, U17.3, U17.6, U18.7, U18.9, U18.10, U18.11, U18.12, U18.13, U19.14, U20.2
GND5: C51.2, C52.2, C53.2, C56.1, C57.2, C60.2, D6.C, J61.1, J62.1, J63.1, J66.1, J66.2, J66.3, J66.4, J68.CD1, J68.GND, J69.6, J71.EARTH, J71.RING2, J72.GND, J72.GND2, J72.SHLD1, J72.SHLD2, J72.SHLD3, J72.SHLD4, J72.SHLD5, J72.SHLD6, J72.SHLD7, J72.SHLD8, JP72.1, JP74.1, R73.1, R76.1, R77.1, U21.3, U21.6, U22.7, U22.9, U22.10, U22.11, U22.12, U22.13, U23.14, U24.2
GND6: C61.2, C62.2, C63.2, C66.1, C67.2, C70.2, D7.C, J73.1, J74.1, J75.1, J78.1, J78.2, J78.3, J78.4, J80.CD1, J80.GND, J81.6, J83.EARTH, J83.RING2, J84.GND, J84.GND2, J84.SHLD1, J84.SHLD2, J84.SHLD3, J84.SHLD4, J84.SHLD5, J84.SHLD6, J84.SHLD7, J84.SHLD8, JP85.1, JP87.1, R86.1, R89.1, R90.1, U25.3, U25.6, U26.7, U26.9, U26.10, U26.11, U26.12, U26.13, U27.14, U28.2
GND7: C71.2, C72.2, C73.2, C76.1, C77.2, C80.2, D8.C, J85.1, J86.1, J87.1, J90.1, J90.2, J90.3, J90.4, J92.CD1, J92.GND, J93.6, J95.EARTH, J95.RING2, J96.GND, J96.GND2, J96.SHLD1, J96.SHLD2, J96.SHLD3, J96.SHLD4, J96.SHLD5, J96.SHLD6, J96.SHLD7, J96.SHLD8, JP98.1, JP100.1, R99.1, R102.1, R103.1, U29.3, U29.6, U30.7, U30.9, U30.10, U30.11, U30.12, U30.13, U31.14, U32.2
GND8: C81.2, C82.2, C83.2, C86.1, C87.2, C90.2, D9.C, J97.1, J98.1, J99.1, J102.1, J102.2, J102.3, J102.4, J104.CD1, J104.GND, J105.6, J107.EARTH, J107.RING2, J108.GND, J108.GND2, J108.SHLD1, J108.SHLD2, J108.SHLD3, J108.SHLD4, J108.SHLD5, J108.SHLD6, J108.SHLD7, J108.SHLD8, JP111.1, JP113.1, R112.1, R115.1, R116.1, U33.3, U33.6, U34.7, U34.9, U34.10, U34.11, U34.12, U34.13, U35.14, U36.2
GND9: C91.2, C92.2, C93.2, C96.1, C97.2, C100.2, D10.C, J109.1, J110.1, J111.1, J114.1, J114.2, J114.3, J114.4, J116.CD1, J116.GND, J117.6, J119.EARTH, J119.RING2, J120.GND, J120.GND2, J120.SHLD1, J120.SHLD2, J120.SHLD3, J120.SHLD4, J120.SHLD5, J120.SHLD6, J120.SHLD7, J120.SHLD8, JP124.1, JP126.1, R125.1, R128.1, R129.1, U37.3, U37.6, U38.7, U38.9, U38.10, U38.11, U38.12, U38.13, U39.14, U40.2
GND10: C101.2, C102.2, C103.2, C106.1, C107.2, C110.2, D11.C, J121.1, J122.1, J123.1, J126.1, J126.2, J126.3, J126.4, J128.CD1, J128.GND, J129.6, J131.EARTH, J131.RING2, J132.GND, J132.GND2, J132.SHLD1, J132.SHLD2, J132.SHLD3, J132.SHLD4, J132.SHLD5, J132.SHLD6, J132.SHLD7, J132.SHLD8, JP137.1, JP139.1, R138.1, R141.1, R142.1, U41.3, U41.6, U42.7, U42.9, U42.10, U42.11, U42.12, U42.13, U43.14, U44.2
GND11: C111.2, C112.2, C113.2, C116.1, C117.2, C120.2, D12.C, J133.1, J134.1, J135.1, J138.1, J138.2, J138.3, J138.4, J140.CD1, J140.GND, J141.6, J143.EARTH, J143.RING2, J144.GND, J144.GND2, J144.SHLD1, J144.SHLD2, J144.SHLD3, J144.SHLD4, J144.SHLD5, J144.SHLD6, J144.SHLD7, J144.SHLD8, JP150.1, JP152.1, R151.1, R154.1, R155.1, U45.3, U45.6, U46.7, U46.9, U46.10, U46.11, U46.12, U46.13, U47.14, U48.2
GND12: C121.2, C122.2, C123.2, C126.1, C127.2, C130.2, D13.C, J145.1, J146.1, J147.1, J150.1, J150.2, J150.3, J150.4, J152.CD1, J152.GND, J153.6, J155.EARTH, J155.RING2, J156.GND, J156.GND2, J156.SHLD1, J156.SHLD2, J156.SHLD3, J156.SHLD4, J156.SHLD5, J156.SHLD6, J156.SHLD7, J156.SHLD8, JP163.1, JP165.1, R164.1, R167.1, R168.1, U49.3, U49.6, U50.7, U50.9, U50.10, U50.11, U50.12, U50.13, U51.14, U52.2
GND13: C131.2, C132.2, C133.2, C136.1, C137.2, C140.2, D14.C, J157.1, J158.1, J159.1, J162.1, J162.2, J162.3, J162.4, J164.CD1, J164.GND, J165.6, J167.EARTH, J167.RING2, J168.GND, J168.GND2, J168.SHLD1, J168.SHLD2, J168.SHLD3, J168.SHLD4, J168.SHLD5, J168.SHLD6, J168.SHLD7, J168.SHLD8, JP176.1, JP178.1, R177.1, R180.1, R181.1, U53.3, U53.6, U54.7, U54.9, U54.10, U54.11, U54.12, U54.13, U55.14, U56.2
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

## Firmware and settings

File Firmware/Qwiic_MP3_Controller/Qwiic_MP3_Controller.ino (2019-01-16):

/*
  Qwiic MP3 Trigger
  By: Nathan Seidle
  SparkFun Electronics
  Date: April 23rd, 2018
  License: This code is public domain but you buy me a beer if you use this and we meet someday (Beerware license).

  An ATtiny84 receives I2C commands from a master and sends/receives commands over serial to the
  WT2003S MP3 player IC. Play, stop, next, previous, and volume control are all accessible over
  I2C. The ATtiny also checks four trigger pins and plays the appropriate track based on which
  trigger pins are pulled low.

  The interrupt pin is active low, open drain. The int pin will go low when a track has completed and
  will remain low until either a track is played or the status of the Qwiic MP3 is queried.

  Available I2C Commands:
  0x00 : Stop
  0x01 then 0x03 : Play file named F003.mp3 - limited to 255
  0x02 then 0x24 : Play file # 36, by index - limited to 255
  0x03 then 15 : Change volume to 15 (half) - limited to 31
  0x04 : Play next
  0x05 : Play previous
  0x06 then 5 : Change Equalizer Setting to bass - 0-normal, 1-pop, 2-rock, 3-jazz, 4-classical, 5-bass
  0x07 then 15 : Set volume to 15. 0(off) to 31(max)
  0x08 : Get available song count on entire SD card
  0x09 : Get song name : Returns an array of 8 bytes
  0x0A : Get play status : 1=playing, 2=stopped, 3=paused
  0x0B : Get card status : Returns true if card is present and mounted
  0x0C : Get firmware version : 2 bytes, upper ver and lower ver
  0x0D : Clear interrupts
  0xC7 : Change I2C address

  Reading data after any command:
  0x00 = OK
  0x01 = Fail, command error, no execution
  0x02 = No such file
  0x05 = SD error

  There are four trigger pins 1, 2, 3, and 4. Pulling pin 2 low will play
  the track named T002.mp3. Pulling pins 1 and 4 low at the same time will
  play track 5. User must name files T001.mp3 to T010.mp3. These are different
  files from the F004.mp3 files that are played using the 'play file name'
  command over I2C.

  Change long:
  v1.1 - Added clear interrupt command. Created Interrupt State Machine.
*/

#include <SoftwareSerial.h>

#if defined(__AVR_ATmega328P__)
SoftwareSerial mp3(6, 4); //RX, TX on dev hardware.
#else
SoftwareSerial mp3(1, 0); //RX, TX on Tiny
#endif

#include <Wire.h>

#include <EEPROM.h>

#include <avr/sleep.h> //Needed for sleep_mode
#include <avr/power.h> //Needed for powering down perihperals such as the ADC/TWI and Timers

//Location in EEPROM where various settings will be stored
#define LOCATION_I2C_ADDRESS 0x01
#define LOCATION_VOLUME 0x02
#define LOCATION_EQ 0x03

//There is an ADR jumpber on this board. When closed, forces I2C address to a given address.
#define I2C_ADDRESS_DEFAULT 0x37
#define I2C_ADDRESS_JUMPER_CLOSED 0x36

//These are the commands we understand and may respond to
#define COMMAND_STOP 0x00
#define COMMAND_PLAY_TRACK 0x01 //Play a given track number like on a CD: regardless of file names plays 2nd file in dir.
#define COMMAND_PLAY_FILENUMBER 0x02 //Play a file # from the root directory: 3 will play F003xxx.mp3
#define COMMAND_PAUSE 0x03 //Will pause if playing, or starting playing if paused
#define COMMAND_PLAY_NEXT 0x04
#define COMMAND_PLAY_PREVIOUS 0x05
#define COMMAND_SET_EQ 0x06
#define COMMAND_SET_VOLUME 0x07
#define COMMAND_GET_SONG_COUNT 0x08 //Note: This causes song to stop playing
#define COMMAND_GET_SONG_NAME 0x09 //Fill global array with 8 characters of the song name
#define COMMAND_GET_PLAY_STATUS 0x0A
#define COMMAND_GET_CARD_STATUS 0x0B
#define COMMAND_GET_VERSION 0x0C
#define COMMAND_CLEAR_INTERRUPTS 0x0D
#define COMMAND_SET_ADDRESS 0xC7

#define SYSTEM_STATUS_OK 0x00
#define SYSTEM_STATUS_FAIL 0x01
#define SYSTEM_STATUS_NO_SUCH_FILE 0x02
#define SYSTEM_STATUS_SD_ERROR 0x05

#define RESPONSE_TYPE_SYSTEM_STATUS 0x00
#define RESPONSE_TYPE_SONG_COUNT 0x01
#define RESPONSE_TYPE_SONG_NAME 0x02
#define RESPONSE_TYPE_PLAY_STATUS 0x03
#define RESPONSE_TYPE_CARD_STATUS 0x04
#define RESPONSE_TYPE_FIRMWARE_VERSION 0x05

#define TASK_NONE 0x00
#define TASK_GET_SONG_NAME 0x01
#define TASK_GET_SONG_COUNT 0x02
#define TASK_GET_PLAY_STATUS 0x03

//Firmware version. This is sent when requested. Helpful for tech support.
const byte firmwareVersionMajor = 1;
const byte firmwareVersionMinor = 1;

//Hardware pins
const byte adr = 9; //Address select jumper is on pin 9
const byte trigger1 = 5; //There are four 'trigger' pins used to trigger the playing of a track
const byte trigger2 = 10;
const byte trigger3 = 8;
const byte trigger4 = 3;
const byte interruptOutput = 7;
const byte playing = 2;

//Variables used in the I2C interrupt so we use volatile
volatile byte systemStatus = SYSTEM_STATUS_OK; //Tracks the response from the MP3 IC

//The MP3 IC can take up to 250ms to respond to a command. We don't want to clock stretch
//after every command so instead, we harvest the system status in the main loop.
volatile boolean getNewStatus = true; //When possible, check MP3 IC for system status

volatile byte responseType = RESPONSE_TYPE_SYSTEM_STATUS; //Tracks how to respond based on incoming requests
volatile char songName[9]; //Loaded with the track name upon request
volatile byte mainLoopTask = 0; //Tracks a request for tasks that must be done in the main loop
volatile byte playStatus = 0; //Tracks the play response. 1=play, 2=stop, 3=pause
volatile byte cardStatus = 0; //Tracks if a card is detected or not

volatile byte settingAddress = I2C_ADDRESS_DEFAULT; //The 7-bit I2C address of this QMP3
volatile byte settingVolume = 0;
volatile byte settingEQ = 0;

//Interrupt turns on when track has completed,
//turns off when interrupts are cleared by command
//And goes to No Int if a song has started playing
enum State {
  STATE_INT = 0,
  STATE_INT_CLEARED,
  STATE_NO_INT
};
volatile byte interruptState = STATE_NO_INT;

byte songCount = 0; //Tracks how many songs are available to play
byte oldTriggerNumber = 0; //Tracks trigger state changes
unsigned long lastCheck = 0; //Tracks the last time we checked if song is playing

void setup()
{
  pinMode(adr, INPUT_PULLUP);
  pinMode(playing, INPUT_PULLUP);

  pinMode(trigger1, INPUT_PULLUP);
  pinMode(trigger2, INPUT_PULLUP);
  pinMode(trigger3, INPUT_PULLUP);
  pinMode(trigger4, INPUT_PULLUP);

  //This will set the int pin to high impedance (aka pulled high by external resistor)
  digitalWrite(interruptOutput, LOW); //Push pin to disable internal pull-ups
  pinMode(interruptOutput, INPUT); //Go to high impedance

  readSystemSettings(); //Load all system settings from EEPROM

  mp3.begin(9600); //WS2003S communicates at 9600bps

  //Verify connection to MP3 IC. But give up after 1000ms
  byte counter = 0;
  while (counter++ < 100)
  {
    clearBuffer(); //Read any stray serial bytes being sent from MP3 ICs
    systemStatus = stopPlaying(); //On power on, stop any playing MP3
    if (systemStatus == 0x00) break; //IC responded OK
    noIntDelay(10); //10ms
  }

  setVolume(settingVolume); //Go to the volume stored in system settings. This can take >150ms
  systemStatus = setEQ(settingEQ); //Set to last EQ setting

#if defined(__AVR_ATmega328P__)
  Serial.begin(115200);
  Serial.println("Qwiic MP3 Controller");
  Serial.print("QMP3 Address: 0x");
  Serial.println(settingAddress, HEX);

  if (systemStatus == 0x00)
    Serial.println("QMP3 online");
  else
  {
    Serial.print("No MP3 found: 0x");
    Serial.println(systemStatus, HEX);
  }
#endif

  //Begin listening on I2C only after we've setup all our config and opened any files
  startI2C(); //Determine the I2C address we should be using and begin listening on I2C bus
}

void loop()
{
  //We can't do serial receive during the I2C interrupt so we do anything that
  //requires a response to a command
  if (mainLoopTask == TASK_GET_SONG_NAME)
  {
    getSongName(); //Load current song name into global array
    mainLoopTask = TASK_NONE; //Reset task to nothing
    responseType = RESPONSE_TYPE_SONG_NAME; //Change response type
  }
  else if (mainLoopTask == TASK_GET_SONG_COUNT)
  {
    songCount = getSongCount();
    mainLoopTask = TASK_NONE; //Reset task to nothing
    responseType = RESPONSE_TYPE_SONG_COUNT; //Change response type
  }

  //Check trigger pins and act accordingly
  if (digitalRead(trigger1) == LOW ||
      digitalRead(trigger2) == LOW ||
      digitalRead(trigger3) == LOW ||
      digitalRead(trigger4) == LOW)
  {
    delay(100); //Debounce/Wait a bit in case user is pulling other pins low

    byte fileNumber = 0;
    if (digitalRead(trigger1) == LOW) fileNumber += 1;
    if (digitalRead(trigger2) == LOW) fileNumber += 2;
    if (digitalRead(trigger3) == LOW) fileNumber += 3;
    if (digitalRead(trigger4) == LOW) fileNumber += 4;

    //Is one of the triggers still activated? More debouncing.
    if (fileNumber > 0)
    {
      //If no song is playing then allow re-triggering by holding down button or trigger
      //This will cause songs to repeat as long as trigger is activated
      if (isPlaying() == false) oldTriggerNumber = 0;

      if (fileNumber != oldTriggerNumber)
      {
        //We have a new trigger!
        if (isPlaying()) stopPlaying(); //Stop any currently playing track
        byte result = playTriggerFile(fileNumber); //Ex: 2 will play T002xxx.mp3

#if defined(__AVR_ATmega328P__)
        Serial.print("result: 0x");
        Serial.println(result, HEX);
#endif

        oldTriggerNumber = fileNumber; //Update the state so we don't play this again
      }//End new trigger number
    }//End fileNumber > 0
  } //End trigger is low
  else
  {
    oldTriggerNumber = 0;
  }


  //Interrupt pin state machine
  //There are three state: No int, Int, and Int Cleared
  //The third state is set in the I2C interrupt when Clear Ints command is received.
  if (interruptState == STATE_NO_INT)
  {
    //Every 100ms check to see if we're done playing the song
    if (millis() - lastCheck > 100)
    {
      lastCheck = millis();

      if (isPlaying() == false)
      {
        //If so, set the interrupt pin low to indicate interrupt
        pinMode(interruptOutput, OUTPUT);
        digitalWrite(interruptOutput, LOW);

        interruptState = STATE_INT; //Go to next state
      }
    }
  }
  else if (interruptState == STATE_INT_CLEARED)
  {
    if (isPlaying() == true)
    {
      interruptState = STATE_NO_INT; //Go to next state
    }
  }
}

//Begin listening on I2C bus as I2C slave using the global variable settingAddress
void startI2C()
{
  Wire.end(); //Before we can change addresses we need to stop

  if (digitalRead(adr) == HIGH) //Default is HIGH.
    Wire.begin(settingAddress); //Start I2C and answer calls using address from EEPROM
  else //User has closed jumper with solder to GND
    Wire.begin(I2C_ADDRESS_JUMPER_CLOSED); //Force address to I2C_ADDRESS_NO_JUMPER if user has opened the solder jumper

  //The connections to the interrupts are severed when a Wire.begin occurs. So re-declare them.
  Wire.onReceive(receiveEvent);
  Wire.onRequest(requestEvent);
}

//Software delay. Does not rely on internal timers.
void noIntDelay(byte amount)
{
  for (byte y = 0 ; y < amount ; y++)
  {
#if defined(__AVR_ATmega328P__)
    for (unsigned int x = 0 ; x < 3000 ; x++) //1ms at 16MHz. Validated with analyzer
#else
    //ATtiny84 at 8MHz
    for (unsigned int x = 0 ; x < 1500 ; x++) //1ms at 8MHz
#endif
    {
      __asm__("nop\n\t");
    }
  }
}

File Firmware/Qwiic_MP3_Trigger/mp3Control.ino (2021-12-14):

//These are the commands that are sent over serial to the WT2003S
#define MP3_COMMAND_PLAY_INDEX_IN_ROOT 0xA2
#define MP3_COMMAND_PLAY_FILE_IN_ROOT 0xA3
#define MP3_COMMAND_PLAY_INDEX_IN_FOLDER 0xA4
#define MP3_COMMAND_PLAY_FILE_IN_FOLDER 0xA5
#define MP3_COMMAND_PAUSE 0xAA
#define MP3_COMMAND_STOP 0xAB
#define MP3_COMMAND_NEXT 0xAC
#define MP3_COMMAND_PREVIOUS 0xAD
#define MP3_COMMAND_SET_VOLUME 0xAE //Can take more than 150ms to complete
#define MP3_COMMAND_SET_EQ_MODE 0xB2

#define MP3_COMMAND_GET_VOLUME 0xC1
#define MP3_COMMAND_GET_CURRENT_STATE 0xC2
#define MP3_COMMAND_GET_SONG_COUNT 0xC5
#define MP3_COMMAND_GET_SONGS_IN_FOLDER_COUNT 0xC6
#define MP3_COMMAND_GET_FILE_PLAYING 0xC9
#define MP3_COMMAND_GET_SONG_NAME_PLAYING 0xCB

#define MP3_START_CODE 0x7E
#define MP3_END_CODE 0xEF

byte commandBytes[11]; //Global array to pass MP3 commands around
//Worst case command may be 0xA3 which could have 8 characters of file name

//Query the total number of music files on the SD card (including sub directories)
//NOTE: This will cause any current playing song to stop
unsigned int getSongCount()
{
  commandBytes[0] = MP3_COMMAND_GET_SONG_COUNT;
  sendCommand(1);

  if (responseAvailable() == false) return (0); //Timeout

  //Get three byte response. Timeout after 250ms
  byte i = 0;
  while (mp3.available() < 3)
  {
    noIntDelay(1);
    if (i++ > 250) return (0); //Error
  }

  unsigned int count = 0xFFFF;
  i = 0;
  while (mp3.available())
  {
    byte incoming = mp3.read();
    if (i == 0) ; //This is throw away value 0xC5
    else if (i == 1) count = (incoming << 8); //MSB
    else if (i == 2) count |= incoming; //LSB

    i++;
  }

  return (count);
}

//Query the song name of the current play
//Caller must provide an array of 9 characters
//We can't do any serial receiving during an interrupt
void getSongName()
{
  commandBytes[0] = MP3_COMMAND_GET_SONG_NAME_PLAYING;
  sendCommand(1);

  strcpy(songName, (char *)"Error\0");
  if (responseAvailable() == false) return;

  //Wait for 9 byte response. Timeout after 250ms
  byte i = 0;
  while (mp3.available() < 9)
  {
    noIntDelay(1);
    if (i++ > 250) return; //Return with Error in songName
  }

  //Parse the response
  i = 0;
  while (mp3.available())
  {
    byte incoming = mp3.read();
    if (i == 0) ; //This is throw away value 0xCB
    else if (i < 9) songName[i - 1] = incoming;

    i++;
  }
  songName[8] = '\0'; //Terminate this string
}

//Play a given track number. This is a number of listed MP3s in the root directory.
//User can arrange the MP3s however. Not necessarily in alpha-order.
//Does nothing if file is not available
byte playTrackNumber(byte trackNumber)
{
  commandBytes[0] = MP3_COMMAND_PLAY_INDEX_IN_ROOT;
  commandBytes[1] = trackNumber >> 8; //MSB
  commandBytes[2] = trackNumber & 0xFF; //LSB
  sendCommand(3);
  byte response = getResponse();

  if (trackPlaying == false) setMP3Volume(settingVolume); //Go to the volume stored in system settings. This can take >150ms
  trackPlaying = true;

  return (response);
}

//Play a file # from the root directory
//For example 3 will play F003xxx.mp3 where x can be anything
//Does nothing if file is not available
byte playFileName(byte fileNumber)
{
  commandBytes[0] = MP3_COMMAND_PLAY_FILE_IN_ROOT;
  commandBytes[1] = 'F';
  commandBytes[2] = '0' + (fileNumber / 100);
  fileNumber %= 100;
  commandBytes[3] = '0' + (fileNumber / 10);
  fileNumber %= 10;
  commandBytes[4] = '0' + fileNumber;
  sendCommand(5);
  byte response = getResponse();

  if (trackPlaying == false) setMP3Volume(settingVolume); //Go to the volume stored in system settings. This can take >150ms
  trackPlaying = true;

  return (response);
}

//Play a file # from the root directory
//For example 1 will play T001xxx.mp3 where x can be anything
//Does nothing if file is not available
byte playTriggerFile(byte triggerNumber)
{
  commandBytes[0] = MP3_COMMAND_PLAY_FILE_IN_ROOT;
  commandBytes[1] = 'T';
  commandBytes[2] = '0' + (triggerNumber / 100);
  triggerNumber %= 100;
  commandBytes[3] = '0' + (triggerNumber / 10);
  triggerNumber %= 10;
  commandBytes[4] = '0' + triggerNumber;
  sendCommand(5);
  byte response = getResponse();

  if (trackPlaying == false) setMP3Volume(settingVolume); //Go to the volume stored in system settings. This can take >150ms
  trackPlaying = true;

  return (response);
}

//Set the internal variable but don't change MP3 IC level
byte setInternalVolume(byte volumeLevel)
{
  if (volumeLevel > 31) volumeLevel = 31; //Error check
  settingVolume = volumeLevel; //Update internal value

#if defined(__AVR_ATmega328P__)
  Serial.print("Set Internal volume to: ");
  Serial.println(settingVolume);
#endif

  if (trackPlaying == true) setMP3Volume(settingVolume);
  return (0);
}

//Set volume. 0 is off. 31 max.
byte setMP3Volume(byte volumeLevel)
{
  if (volumeLevel > 31) volumeLevel = 31; //Error check
  //
  //  settingVolume = volumeLevel; //Update internal value
  //
  //if(trackPlaying == false) return(settingVolume); //Autoloop work around: If we're ignoring the auto-loop playing, don't turn up volume.

  //If we are actively playing, go ahead and set volume
  commandBytes[0] = MP3_COMMAND_SET_VOLUME;
  commandBytes[1] = volumeLevel;
  sendCommand(2);
  byte response = getResponse();

#if defined(__AVR_ATmega328P__)
  Serial.print("SetMP3volume to: ");
  Serial.println(volumeLevel);
#endif

  return (response);
}

//Returns the current volume level, 0 to 31
byte getVolume(void)
{
  return (settingVolume); //Rather than poll IC, just return local var
  /*commandBytes[0] = MP3_COMMAND_GET_VOLUME;
    sendCommand(1);

    //Get two byte response
    unsigned int volLevel = getTwoByteResponse();

    //First byte is 0xC1, second byte is volume level
    return (volLevel & 0xFF);*/
}

//Set the equalizer levels to one of 6 levels (normal, pop, rock, jazz, classic, bass)
byte setEQ(byte eqType)
{
  if (eqType > 5) eqType = 0; //Error check. Set to normal by default
  commandBytes[0] = MP3_COMMAND_SET_EQ_MODE;
  commandBytes[1] = eqType;
  sendCommand(2);
  return (getResponse());
}

//Returns the current EQ setting: one of 6 levels (normal, pop, rock, jazz, classic, bass)
byte getEQ()
{
  return (settingEQ);
}

//Checks status. Returns true if a song is playing (status 0x01)
//01: play, 02: stop, 03: pause
boolean isPlaying(void)
{
  if (digitalRead(playing) == HIGH) return (true); //Song is playing
  return (false);

  //if(getPlayStatus() == 0x01) return (true);
  //return (false);
}

//Returns the current play/stop/pause status
//01: play, 02: stop, 03: pause
byte getPlayStatus(void)
{
  //  commandBytes[0] = MP3_COMMAND_GET_CURRENT_STATE;
  //  sendCommand(1);
  //  return (getTwoByteResponse() & 0xFF);

  if (trackPlaying == true) return (1); //Playing
  else return (2); //Stop
}
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

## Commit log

2018-04-15 Removing extra files
    [JQ8400-FL语音模块原理图V1.1.SchDoc]
2018-04-25 Fixed errors. V02 ready
    Added AC caps to headphones. 3.3V now gets through on MP3 IC. 100k swap on amp to make less loud. More decoupling. Fixed trigger numbering.
    [Qwiic MP3-Panel.GBL, Qwiic MP3-Panel.GBO, Qwiic MP3-Panel.GBP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]
2018-05-01 Adding basic firmware
    [Qwiic MP3-Panel.GBL, Qwiic MP3-Panel.GBO, Qwiic MP3-Panel.GBP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]
2018-05-08 Working code
    [Qwiic MP3-Panel.brd, Qwiic MP3.brd]
2018-05-10 Nearing production code
    [Qwiic MP3.brd, Qwiic MP3.sch]
2018-05-10 Small schematic note change
    [Qwiic MP3.brd, Qwiic MP3.sch]
2018-06-04 Fix for issue 3
    [Qwiic_MP3_Controller.ino]
2018-06-20 Revert "OddCommit"
    This reverts commit 5cd89683eb1f2e7621ff14169c194c3af59dd775.
    [Board_Design_Checklist_MP3 Breakout WT2003S_01.xls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]
2018-11-19 Update to USB C
    [Qwiic MP3.brd, Qwiic MP3.sch]
2018-11-19 File name clean up.
    [Qwiic MP3 Trigger.brd, Qwiic MP3 Trigger.sch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]
2018-11-19 Fixing product name silk. Adding production panel.
    [Qwiic MP3 Trigger-Panel.GBL, Qwiic MP3 Trigger-Panel.GBO, Qwiic MP3 Trigger-Panel.GBP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]
2018-11-29 Routing Playing pin on WS to Shutdown pin on amp
    [Qwiic MP3 Trigger.brd, Qwiic MP3 Trigger.sch]
2018-11-29 Rolling to v11 copper
    [Qwiic MP3 Trigger.brd, Qwiic MP3 Trigger.sch]
2019-01-12 Adding production panel files for v11 reds
    [Qwiic MP3 Trigger-Panel.GBL, Qwiic MP3 Trigger-Panel.GBO, Qwiic MP3 Trigger-Panel.GBP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]
2021-11-17 Mute volume to prevent auto-loop bug.
    [Qwiic_MP3_Trigger.ino, mp3Control.ino]

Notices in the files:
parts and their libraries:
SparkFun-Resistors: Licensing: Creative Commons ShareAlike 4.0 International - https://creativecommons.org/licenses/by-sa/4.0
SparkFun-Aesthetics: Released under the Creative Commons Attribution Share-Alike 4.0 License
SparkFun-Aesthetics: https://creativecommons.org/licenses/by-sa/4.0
